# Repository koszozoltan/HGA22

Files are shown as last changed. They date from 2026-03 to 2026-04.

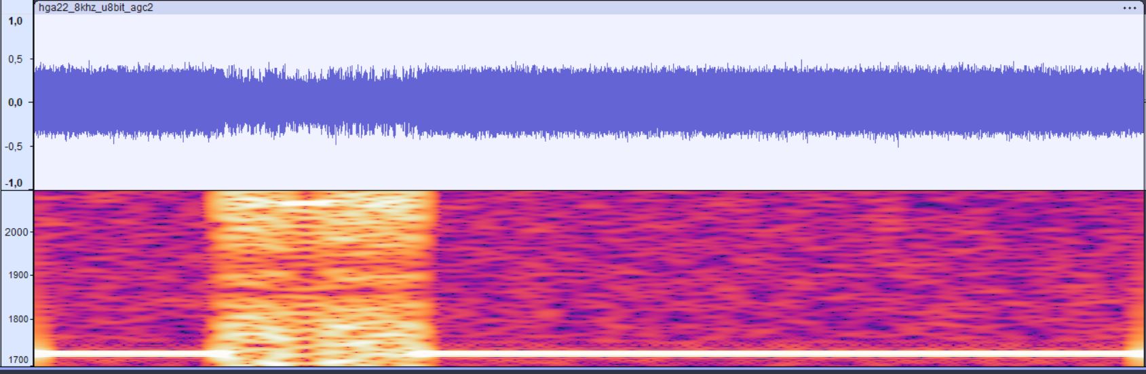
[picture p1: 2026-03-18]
docs/hga22_8khz_u8bit_agc2.jpg

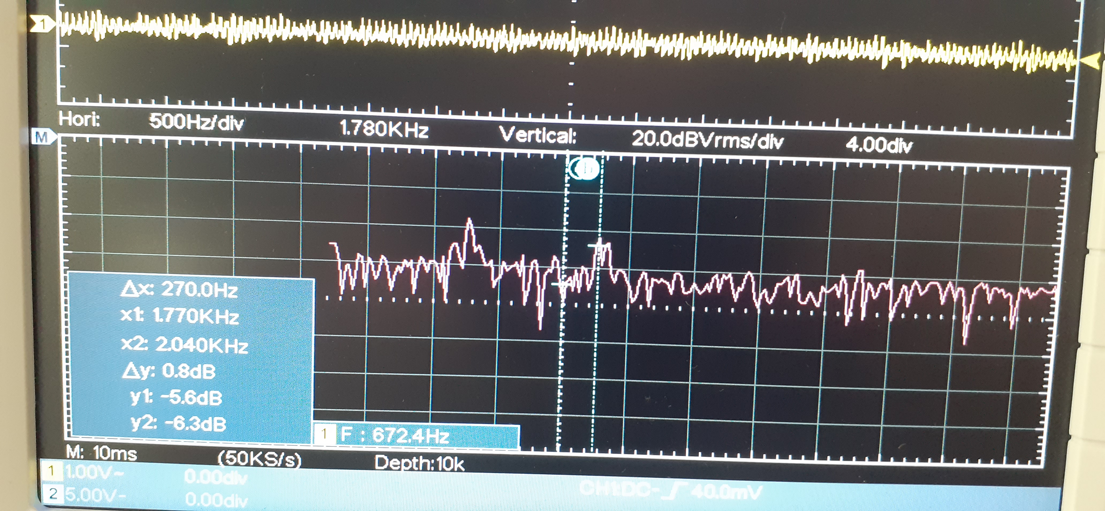
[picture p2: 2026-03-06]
docs/20260227_095744.jpg

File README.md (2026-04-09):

HGA22 Time Signal Receiver
This project is used to receive and decode the time signals broadcasted at 135.6 kHz by the HGA22 transmitter station in Lakihegy. The system is capable of processing phase-shift keying (FSK) signals and extracting time information.

https://github.com/5an2i/USB_HGA22

📋 Features
Frequency: 135.6 kHz (LF band)

Modulation: FSK

Platform: STM32C071 Nucleo
Data format: Serial, RNDIS USB - NTP
🛠️ Hardware architecture
The following components were required for reception:

Antenna: [Ferrite rod or RFID reader antenna] tuned to 135.6 kHz.

HGA22 Time Signal Receiver
Ez a projekt a lakihegyi HGA22 adóállomás 135,6 kHz-en sugárzott pontos idő jeleinek vételére és dekódolására szolgál. A rendszer képes a fázismodulált (FSK) jelek feldolgozására és az időinformáció kinyerésére.

📋 Jellemzők
Frekvencia: 135,6 kHz (LF sáv)

Moduláció: FSK

Platform: STM32C071 Nucleo
Adatformátum: Soros , RNDIS USB - NTP 
🛠️ Hardver felépítés
A vételhez az alábbi komponensekre volt szükség:

Antenna: [Ferrit rúd vagy RFID olvasó antenna] 135,6 kHz-re hangolva.

1. Mi az a HGA22?
A HGA22 egy hosszúhullámú (LF) rádióadó Lakihegyen, amely 135,6 kHz-en sugároz. Ez az EFR (Europäische Funk-Rundsteuerung) hálózat része, amit elsősorban távvezérlésre (pl. utcai világítás, „éjszakai áram”) és pontos idő szinkronizációra használnak.

Frekvencia: 135,6 kHz

Adatsebesség: 200 bps (Baud)

Szerepe: Alternatíva a német DCF77-re, de nagyobb adatsebességgel és gyakrabban küldött időinformációval rendelkezik (akár 10 másodpercenként).

2. A Moduláció: FSK (Frequency Shift Keying)
A digitális adatokat frekvenciabillentyűzéssel kódolják. Ez azt jelenti, hogy a logikai '0' és '1' szinteket két különböző frekvencia képviseli a vivőfrekvencia körül.

Shift (löket): ±170 Hz

Frekvenciák: * F_low: 135,430 kHz (Space / 0)

F_high: 135,770 kHz (Mark / 1)
A vevő dolga, hogy eldöntse: éppen melyik frekvencia „szól”.

3. A Matematikai Motor: Goertzel-algoritmus
Hogyan detektáljunk egy konkrét frekvenciát kevés számítási kapacitással? Itt jön a Goertzel-algoritmus. Ez egy speciális IIR (Infinite Impulse Response) szűrő, amely a Diszkrét Fourier-transzformáció (DFT) egyetlen komponensét számolja ki.

Miért jobb, mint az FFT?
Mivel nekünk csak két konkrét frekvenciát (a löket alatti és feletti értékeket) kell figyelnünk, felesleges a teljes spektrumot kiszámolni. A Goertzel sokkal gyorsabb mikrokontrolleren.

A kódunkban két Goertzel szűrő fut párhuzamosan. Amelyik kimenetén nagyobb az „energia” (amplitúdó), azt a bitet tekintjük érvényesnek.

4. HGA22 Frame Parsolás (Keretezés)
Az adatok nem ömlesztve jönnek, hanem kötött szerkezetű táviratokban (frames). A protokoll (hasonlóan a Versacom-hoz) az alábbi módon épül fel:

Start karakter: 0x68 (ez jelzi a csomag elejét).

Hossz: Megadja, hány bájt következik.

Ismételt Hossz és Start: Biztonsági ellenőrzés.

Címzés: Megadja, kinek szól az üzenet (az időjel címe általában 0x00).

Adat (Payload): Itt van a lényeg! BCD kódolással tartalmazza az évet, hónapot, napot, órát, percet és másodpercet.

Checksum (CRC): Hibaellenőrzés.

Stop karakter: 0x16.

A kódban (main.cpp):
A parsoló egy állapotgépet (State Machine) használ. Addig dobálja el a bejövő bájtokat, amíg nem talál egy 0x68-at, majd elkezdi feltölteni a puffert a megadott hossz alapján.

https://cmake.org/download/

https://www.codeblocks.org/

https://developer.arm.com/downloads/-/arm-gnu-toolchain-downloads

https://sourceforge.net/projects/gnuwin32/

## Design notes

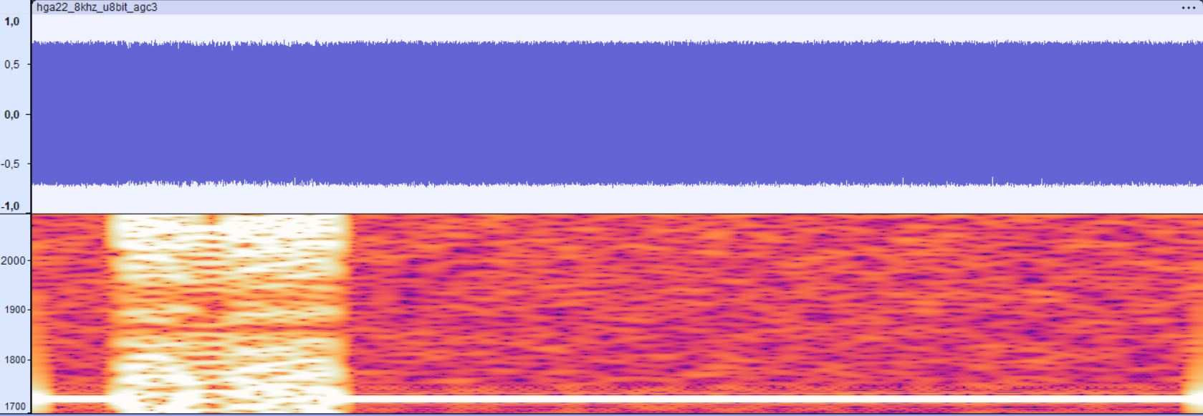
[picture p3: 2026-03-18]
docs/hga22_8khz_u8bit_agc3.jpg

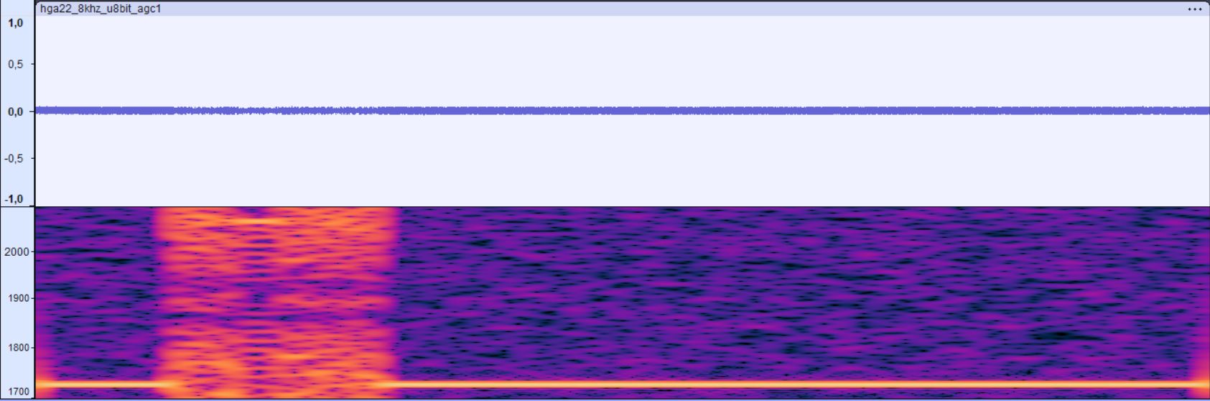
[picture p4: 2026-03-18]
docs/hga22_8khz_u8bit_agc1.jpg

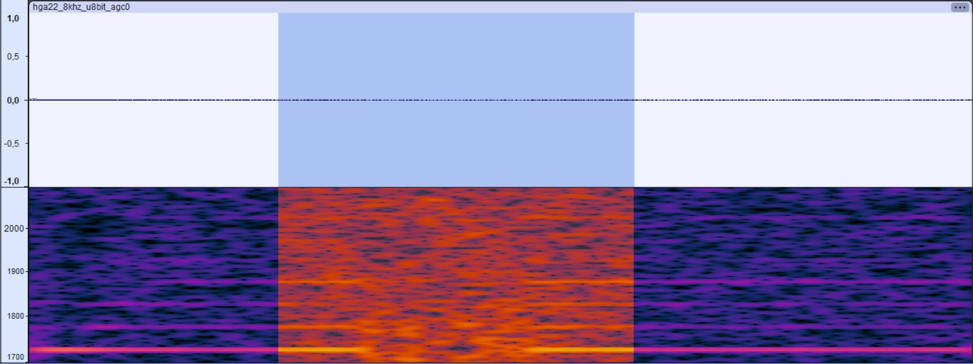
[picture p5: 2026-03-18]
docs/hga22_8khz_u8bit_agc0.jpg

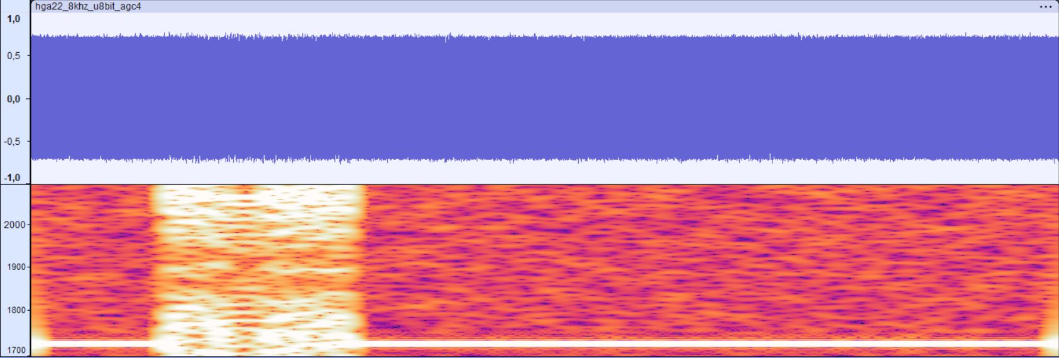
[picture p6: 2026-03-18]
docs/hga22_8khz_u8bit_agc4.jpg

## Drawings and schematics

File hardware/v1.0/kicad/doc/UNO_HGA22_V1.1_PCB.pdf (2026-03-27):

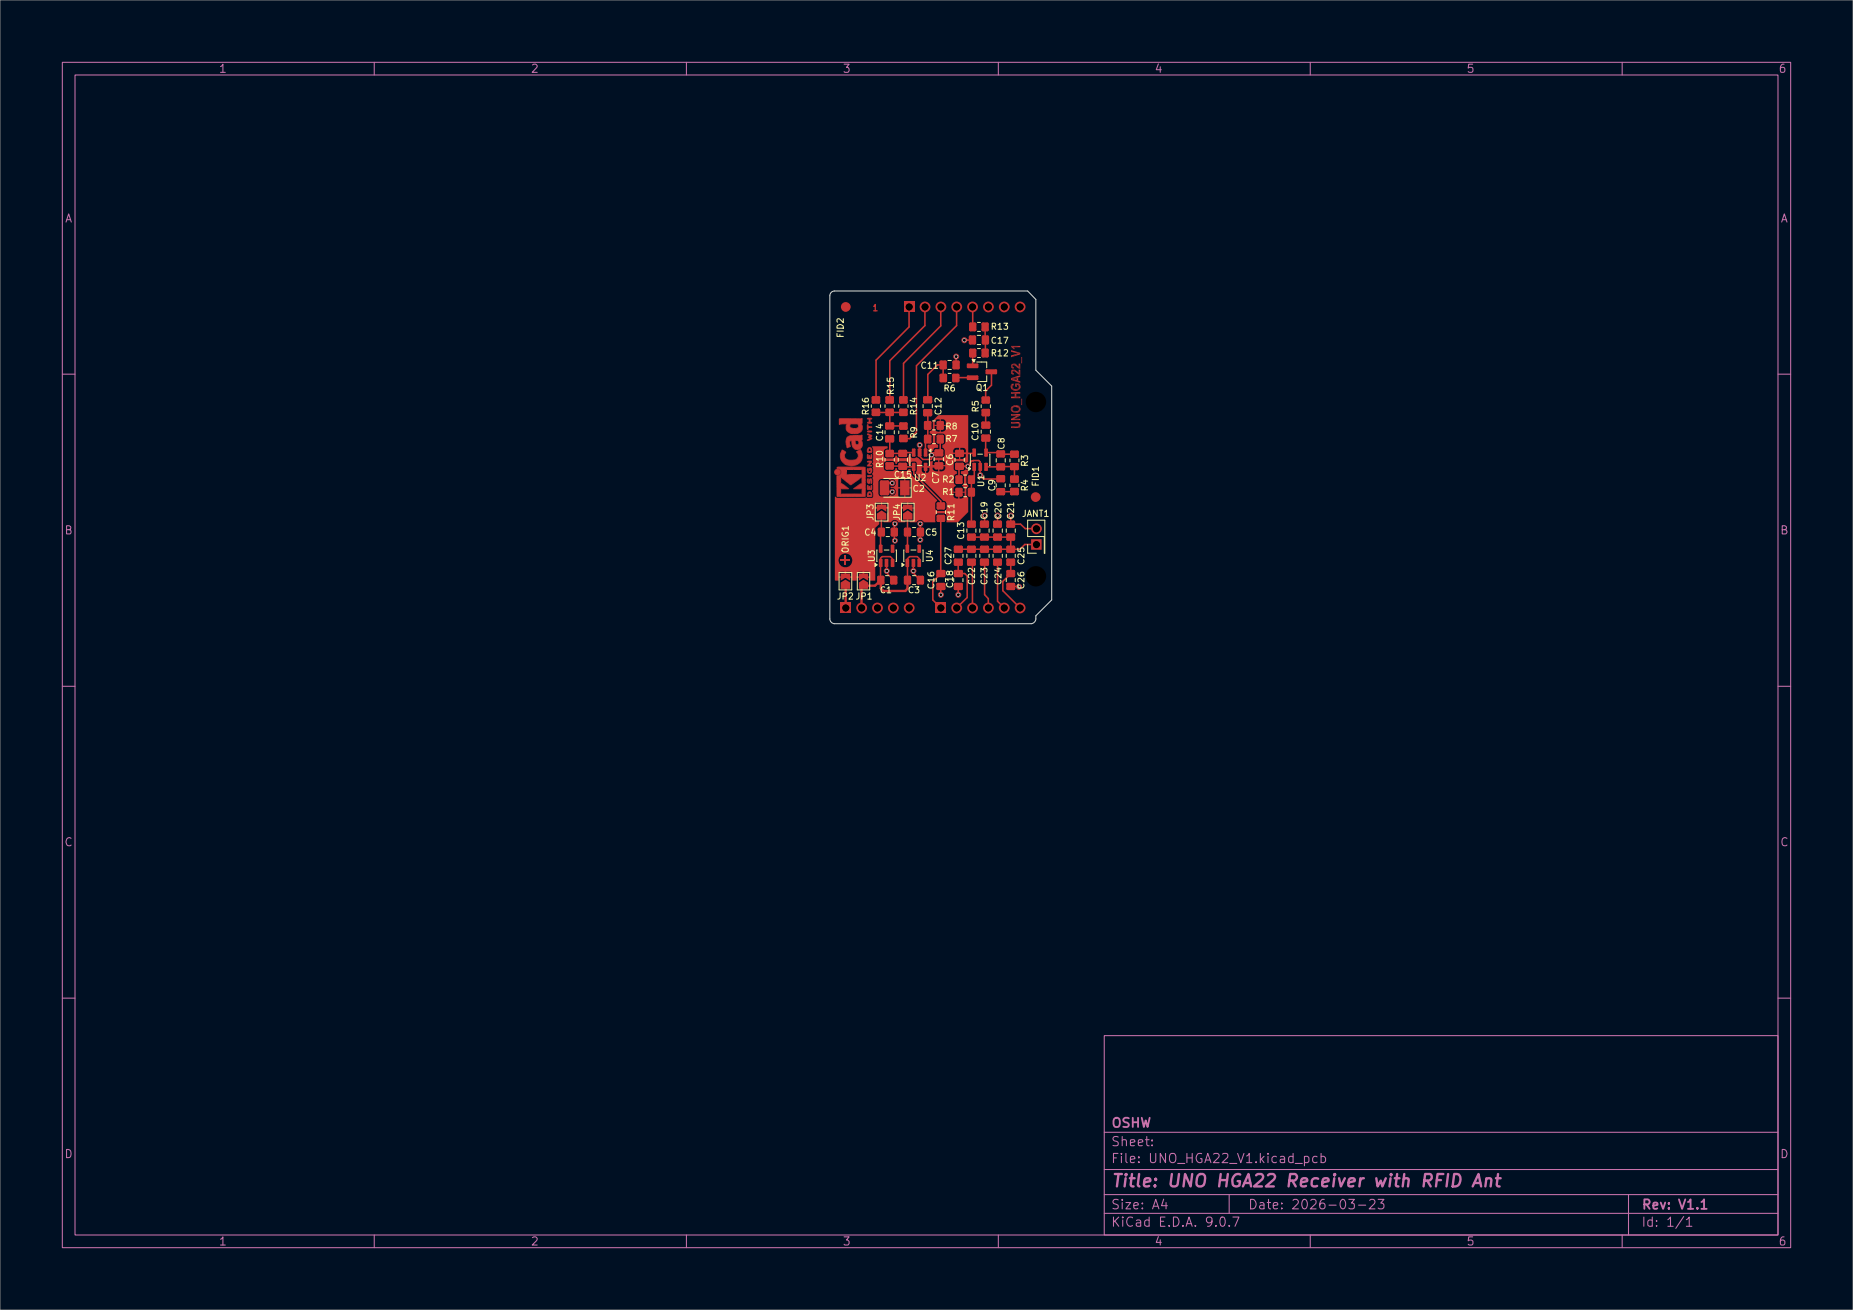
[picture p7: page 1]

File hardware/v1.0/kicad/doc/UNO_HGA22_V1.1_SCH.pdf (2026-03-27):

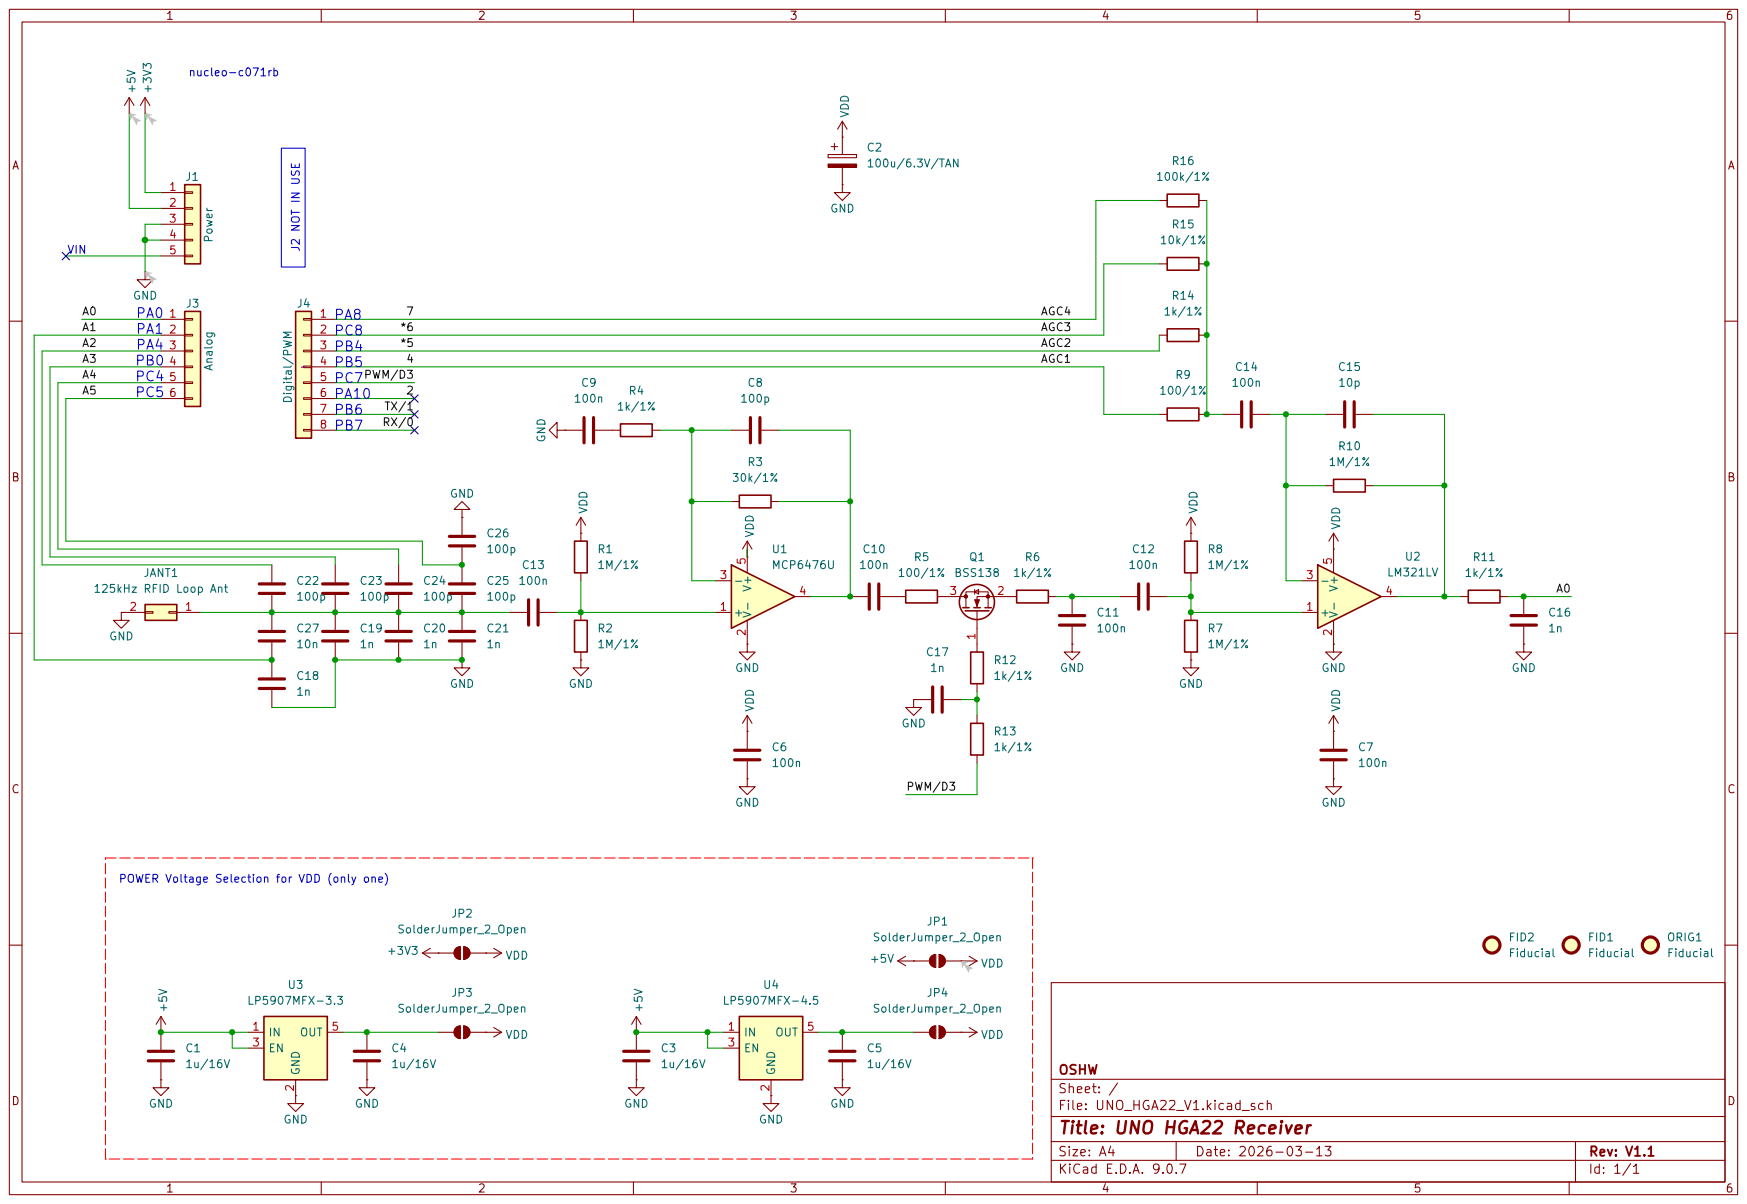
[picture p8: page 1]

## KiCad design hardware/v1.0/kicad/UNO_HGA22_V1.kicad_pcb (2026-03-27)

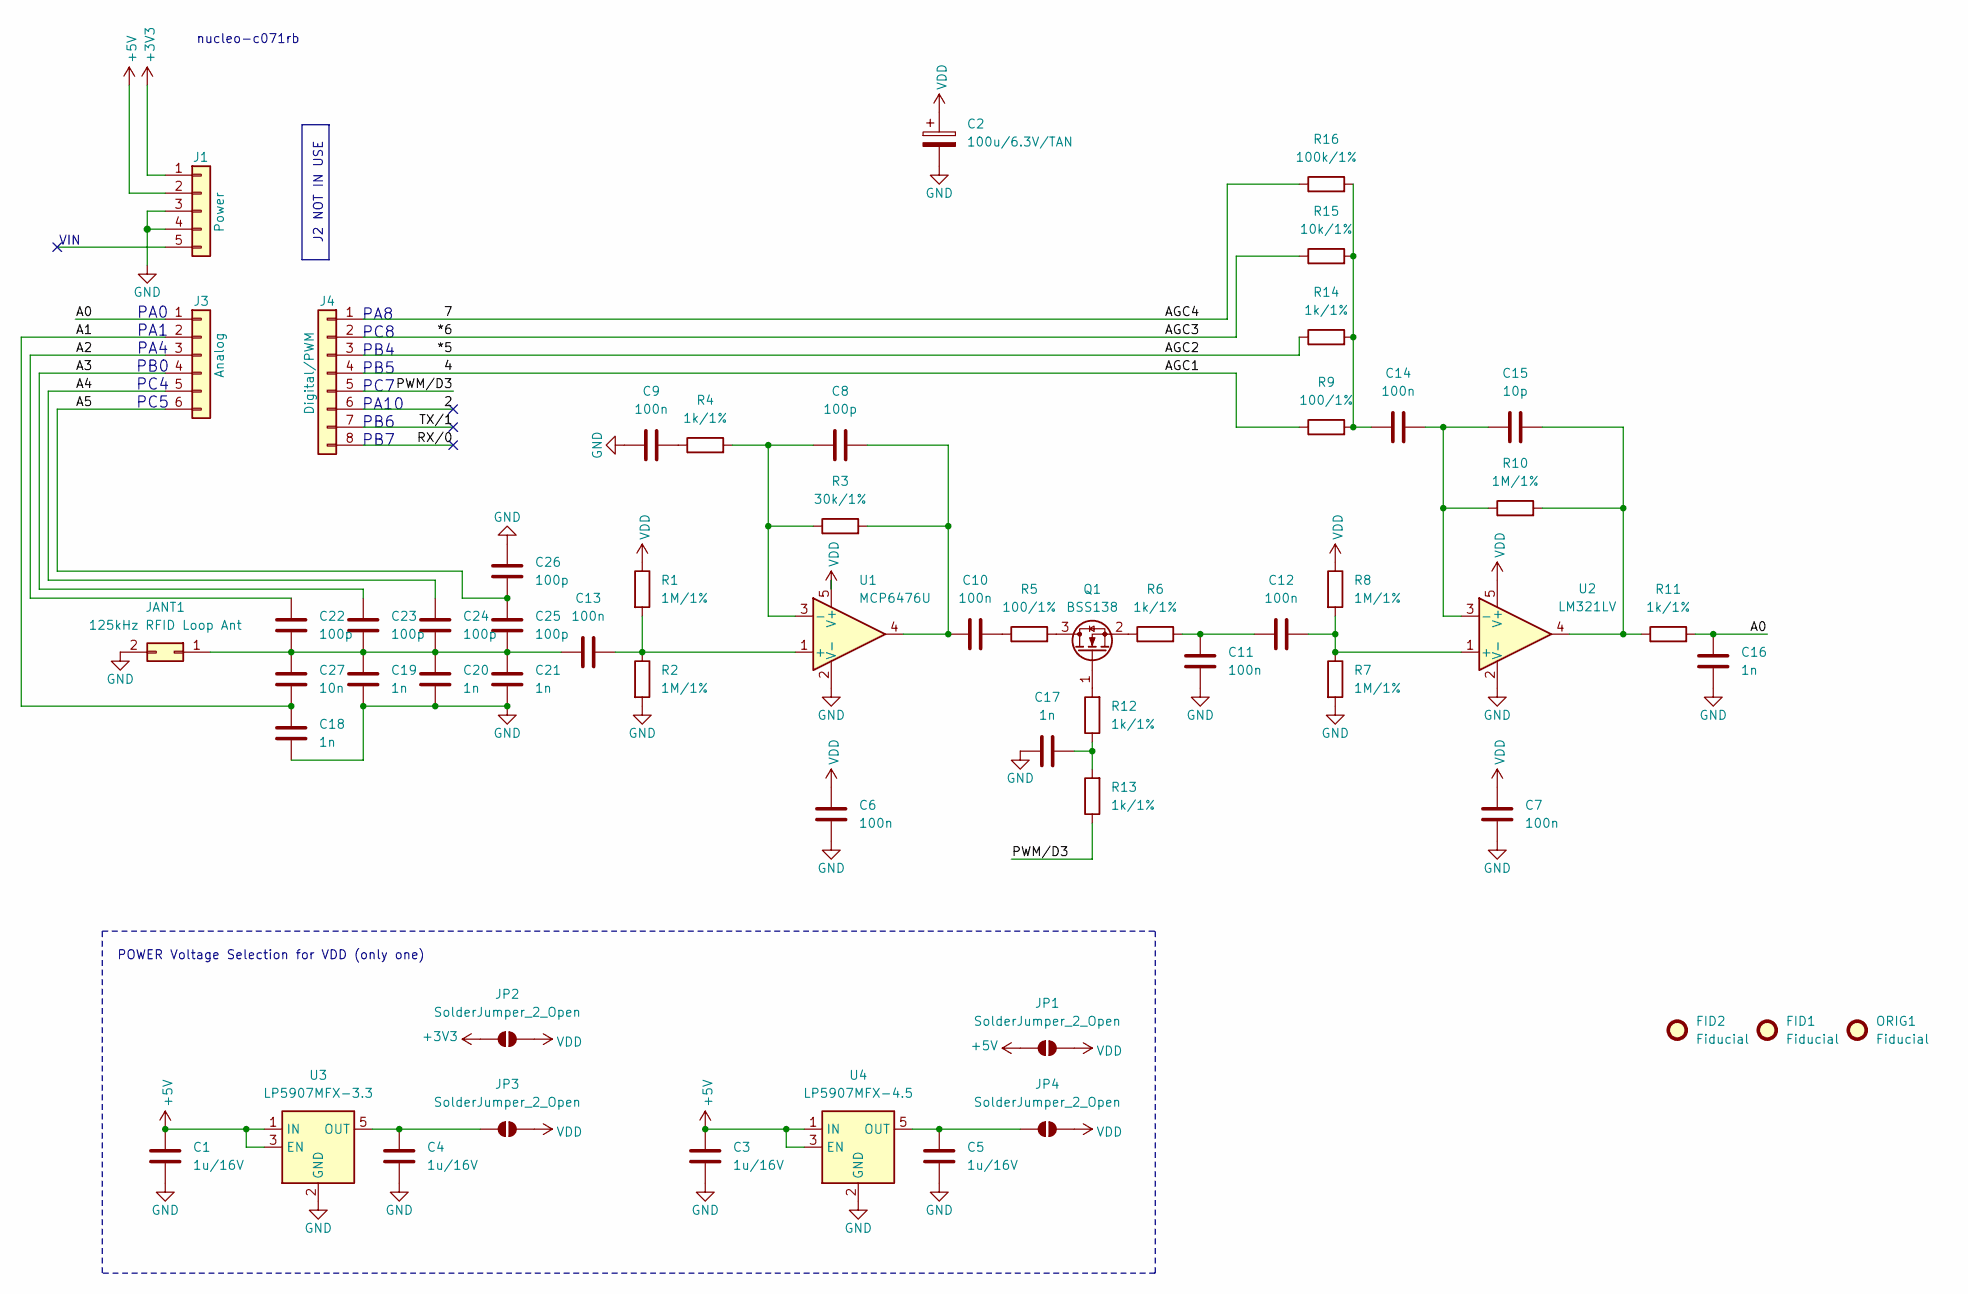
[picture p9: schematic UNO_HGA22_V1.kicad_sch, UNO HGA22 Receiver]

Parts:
C1, C3, C4, C5: 1u/16V; C_0805_2012Metric_Pad1.18x1.45mm_HandSolder
C2: 100u/6.3V/TAN; CP_EIA-3528-21_Kemet-B_HandSolder
C6, C7, C9, C10, C11, C12, C13, C14: 100n; C_0805_2012Metric_Pad1.18x1.45mm_HandSolder
C8, C22, C23, C24, C25, C26: 100p; C_0805_2012Metric_Pad1.18x1.45mm_HandSolder
C15: 10p; C_0805_2012Metric_Pad1.18x1.45mm_HandSolder
C16, C17, C18, C19, C20, C21: 1n; C_0805_2012Metric_Pad1.18x1.45mm_HandSolder
C27: 10n; C_0805_2012Metric_Pad1.18x1.45mm_HandSolder
FID1, FID2: Fiducial; Fiducial_1.5mm_Mask3mm
J1: Power; PinHeader_1x05_P2.54mm_Vertical
J3: Analog; PinHeader_1x06_P2.54mm_Vertical
J4: Digital/PWM; PinHeader_1x08_P2.54mm_Vertical
JANT1: 125kHz RFID Loop Ant; PinHeader_2x01_P2.54mm_Vertical
JP1, JP2, JP3, JP4: SolderJumper_2_Open; SolderJumper-2_P1.3mm_Open_TrianglePad1.0x1.5mm
ORIG1: Fiducial; Fiducial_Cross_1.5mm_Mask2mm
Q1: BSS138; SOT-23_Handsoldering
R1, R2, R7, R8, R10: 1M/1%; R_0805_2012Metric_Pad1.20x1.40mm_HandSolder
R3: 30k/1%; R_0805_2012Metric_Pad1.20x1.40mm_HandSolder
R4, R6, R11, R12, R13, R14: 1k/1%; R_0805_2012Metric_Pad1.20x1.40mm_HandSolder
R5, R9: 100/1%; R_0805_2012Metric_Pad1.20x1.40mm_HandSolder
R15: 10k/1%; R_0805_2012Metric_Pad1.20x1.40mm_HandSolder
R16: 100k/1%; R_0805_2012Metric_Pad1.20x1.40mm_HandSolder
U1: MCP6476U; SOT-23-5
U2: LM321LV; SOT-23-5
U3: LP5907MFX-3.3; SOT-23-5
U4: LP5907MFX-4.5; SOT-23-5

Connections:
+3V3: J1.1, JP2.1 (A)
+5V: C1.1, C3.1, J1.2, JP1.1 (A), U3.1 (IN), U3.3 (EN), U4.1 (IN), U4.3 (EN)
/2: J4.6
/4: J4.4, R9.1
/7: J4.1, R16.1
/*5: J4.3, R14.1
/*6: J4.2, R15.1
/A0: C16.1, J3.1, R11.2
/A1: C18.1, C27.2, J3.2
/A2: C22.2, J3.3
/A3: C23.2, J3.4
/A4: C24.2, J3.5
/A5: C25.2, C26.1, J3.6
/PWM/D3: J4.5, R13.1
/RX/0: J4.8
/TX/1: J4.7
GND: C1.2, C2.2, C3.2, C4.2, C5.2, C6.2, C7.2, C9.1, C11.2, C16.2, C17.1, C18.2, C19.2, C20.2, C21.2, C26.2, J1.3, J1.4, JANT1.2, R2.2, R7.2, U1.2 (V-), U2.2 (V-), U3.2 (GND), U4.2 (GND)
unnamed: C9.2, R4.1
unnamed: C8.2, C10.1, R3.2, U1.4
unnamed: C10.2, R5.1
unnamed: C11.1, C12.1, R6.2
unnamed: C14.1, R9.2, R14.2, R15.2, R16.2
unnamed: C15.2, R10.2, R11.1, U2.4
unnamed: C17.2, R12.1, R13.2
unnamed: C13.1, C19.1, C20.1, C21.1, C22.1, C23.1, C24.1, C25.1, C27.1, JANT1.1
unnamed: C4.1, JP3.1 (A), U3.5 (OUT)
unnamed: C5.1, JP4.1 (A), U4.5 (OUT)
unnamed: Q1.3 (D), R5.2
unnamed: Q1.1 (G), R12.2
unnamed: Q1.2 (S), R6.1
unnamed: C13.2, R1.2, R2.1, U1.1 (+)
unnamed: C8.1, R3.1, R4.2, U1.3 (-)
unnamed: C12.2, R7.1, R8.2, U2.1 (+)
unnamed: C14.2, C15.1, R10.1, U2.3 (-)
VDD: C2.1, C6.1, C7.1, JP1.2 (B), JP2.2 (B), JP3.2 (B), JP4.2 (B), R1.1, R8.1, U1.5 (V+), U2.5 (V+)

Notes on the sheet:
J2 NOT IN USE
PA0 PA1 PA4 PB0 PC4 PC5
VIN
PA8 PC8 PB4 PB5 PC7 PA10 PB6 PB7
POWER Voltage Selection for VDD (only one)
nucleo-c071rb

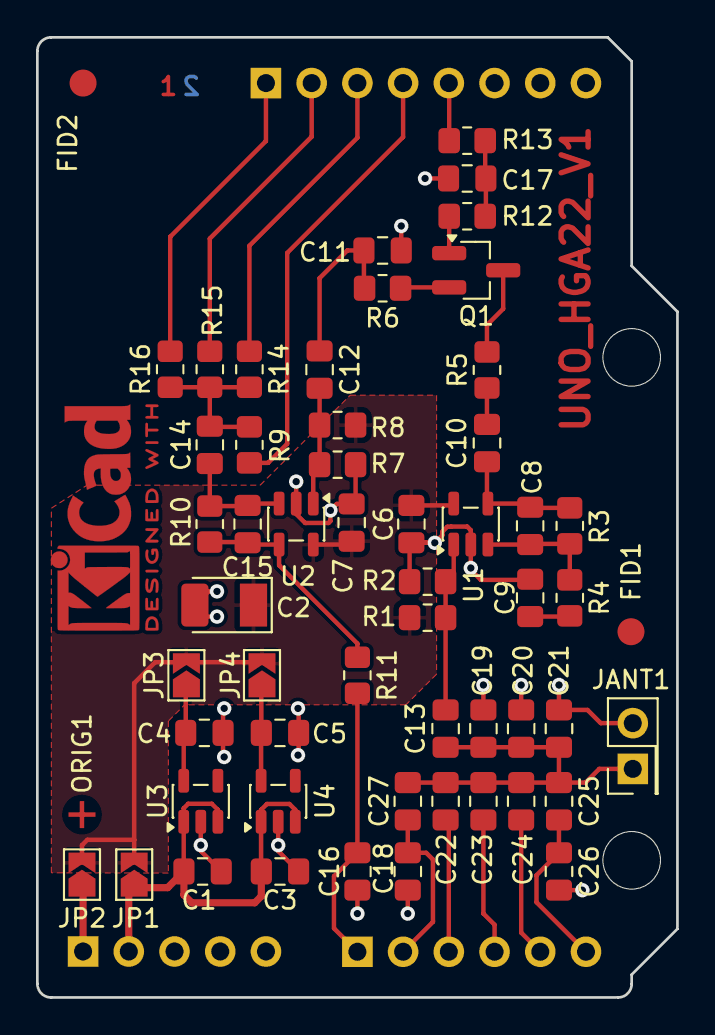
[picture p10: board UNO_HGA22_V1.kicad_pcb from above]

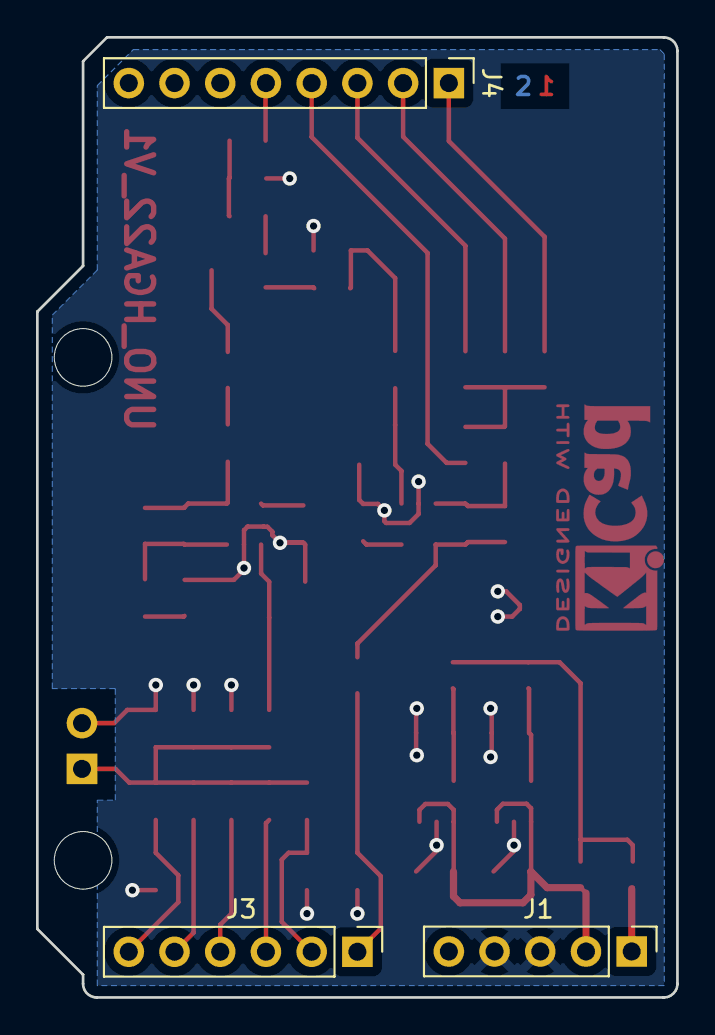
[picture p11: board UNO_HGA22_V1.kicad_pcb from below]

Board: 2 copper layers, 35.6 x 53.3 mm, 61 parts (3 on the bottom side), 32 nets.

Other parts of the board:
MH3, MH4: MountingHole_3.2mm

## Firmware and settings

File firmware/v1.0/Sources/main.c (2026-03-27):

/* USER CODE BEGIN Header */
/**
  ******************************************************************************
  * @file    UART/UART_Printf/Src/main.c
  * @author  MCD Application Team
  * @brief   This example shows how to retarget the C library printf function
  *          to the UART.
  ******************************************************************************
  * @attention
  *
  * Copyright (c) 2024 STMicroelectronics.
  * All rights reserved.
  *
  * This software is licensed under terms that can be found in the LICENSE file
  * in the root directory of this software component.
  * If no LICENSE file comes with this software, it is provided AS-IS.
  *
  ******************************************************************************
  */

/* Includes ------------------------------------------------------------------*/
#include "main.h"
#include "util.h"
#include <string.h>
#include "queue.h"
#include "math.h"
#include "ringbuffer.h"
#include "tcp_server.h"
#include "arm_math.h"
#include "date.h"
#include "adc.h"
#include "iq.h"
#include "goertzel.h"
#include "decoder.h"








UART_HandleTypeDef huart2;

__IO uint32_t uwMeasuredDutyCycle = 0;

/* TIM2 Clock */
static uint32_t TimOutClock = 1;
uint32_t timxPrescaler = 0;
uint32_t timxPeriod = 0;

void Error_Handler2(int);
static void SystemClockHSIUSB48_Config(void);
static inline void board_clock_init(void) ;

int cap = 0;
int agc = 0;
float snr = 0;
int send_array = 0;
int send_snr   = 0;
int search = 0;



int agc_disable = 0;
int min = 65536;
int max = -1;




volatile uint64_t unix_us = 0;// += 1000ULL;


void SystemClock_Config(void);
static void MX_GPIO_Init(void);
static void MX_USART2_UART_Init(void);
static void Timer3Init(void);

/* USER CODE BEGIN PFP */

void ADC_Init(void);
void ADC_Activate(void);
void LED_On(void);
void LED_Off(void);
void LED_Toggle(void);


void RFC1_low(void);
void RFC1_high(void);
void RFC2_low(void);
void RFC2_high(void);
void RFC3_low(void);
void RFC3_high(void);
void RFC4_low(void);
void RFC4_high(void);



void unix_us_to_datetime(uint64_t unix_us, datetime_t *dt);
uint64_t datetime_to_unix_us(const datetime_t *dt, uint32_t usec);

extern void udp_server_init(void);
extern void ShellTask(void);

int Get_HW_Agc(void);



#define PUTCHAR_PROTOTYPE int __io_putchar(int ch)












uint16_t signal_buffer[128];
stream_q_t q_signal;




size_t board_get_unique_id(uint8_t id[], size_t max_len) {
  (void) max_len;
  volatile uint32_t * stm32_uuid = (volatile uint32_t *) UID_BASE;
  uint32_t* id32 = (uint32_t*) (uintptr_t) id;
  uint8_t const len = 12;

  id32[0] = stm32_uuid[0];
  id32[1] = stm32_uuid[1];
  id32[2] = stm32_uuid[2];

  return len;
}






extern void loop_tinyusb (void);
extern int main_tinyusb(void);

//void init_demods(void);


/**
  * @brief  The application entry point.
  * @retval int
  */
int main(void)
{

  HAL_Init();
  BSP_LED_Init(LED1);
  BSP_LED_Init(LED2);
  //SystemClockHSIUSB48_Config() ;
  board_clock_init();

  HAL_Init();


  sq_init(&q_signal, (int16_t*)signal_buffer, 128);
 // sq_init(&q_byte,   (int16_t*)byte_buffer, 32);
 // sq_init(&q_fsk,    (int16_t*)fsk_buffer, 8);
  #if 0
  sq_init(&q_voice,voice_buffer,8192);
  #endif




  MX_GPIO_Init();
  MX_USART2_UART_Init();
  Timer3Init();


  ADC_Init();





  Uart2_printf("\r\nHGA22 RECEIVER RNDIS V1.0>\r\n");
  Uart2_printf("%s %s\r\n", BUILD_DATE);

  Uart2_rx_printf("-h\r\n");
  Uart2_rx_printf("?\r\n");


  {
	  datetime_t dt;

	   dt.yr  = 2026;
	   dt.mon = 1;
	   dt.day = 1;
	   dt.hr  = 0;
	   dt.min = 0;
	   dt.sec = 0;

	   uint64_t now = datetime_to_unix_us(&dt, 0);

	   /* RTC -> dt mezők feltöltése */
	   NVIC_DisableIRQ(SysTick_IRQn);
	   unix_us = now;
	   NVIC_EnableIRQ(SysTick_IRQn);
  }


  RFC1_low();
  RFC2_low();
  RFC3_low();
  RFC4_low();

  AGC1_high();
  AGC2_high();
  AGC3_low();
  AGC4_low();

	__HAL_RCC_USB_CLK_ENABLE();
	__HAL_RCC_GPIOA_CLK_ENABLE();
	__HAL_RCC_GPIOB_CLK_ENABLE();
	__HAL_RCC_GPIOC_CLK_ENABLE();
	__HAL_RCC_GPIOD_CLK_ENABLE();
	__HAL_RCC_SYSCFG_CLK_ENABLE();
	__HAL_RCC_PWR_CLK_ENABLE();
#if 1
  main_tinyusb();
  udp_server_init();

#endif

init_demods();


  while(1){

	  ShellTask();

	  loop_tinyusb();


	  if(ubDmaTransferStatus == 1) {
		  //LED_On();




		  static int send_snr_cnt = 0;
		  if (send_snr){
			  if (++send_snr_cnt >= 1000){
				  send_snr_cnt = 0;
				  Uart2_printf("SNR : %d , min %d, max %d\r\n", (int)snr, (int)min, (int) max );
			  }
		  }

		  static int buffer_size = (SAMPLE_RATE / 1000) * 4;

		   if (sq_size(&q_signal) >= buffer_size){

			   int16_t buffer[buffer_size];


			   sq_peek(&q_signal,buffer,buffer_size);
			   sq_discard(&q_signal,(SAMPLE_RATE / 1000));

			   if (search){
                    if (++send_snr_cnt >= 200){
                        send_snr_cnt = 0;
                        search_freq((uint16_t *)buffer,buffer_size);
                    }
			   }

			   loop(buffer,(SAMPLE_RATE / 1000) * 4);
			   //LED_Off();

		   }

		  //LED_Off();
		  ubDmaTransferStatus = 0;
	  }


  }


}

uint32_t board_button_read(void) {
	return USER_BUTTON_STATE_ACTIVE == HAL_GPIO_ReadPin(USER_BUTTON_GPIO_Port, USER_BUTTON_Pin);
}



static void MX_TIM3_Init(void) {



  LL_TIM_InitTypeDef TIM_InitStruct = {0};
  LL_TIM_OC_InitTypeDef TIM_OC_InitStruct = {0};

  LL_GPIO_InitTypeDef GPIO_InitStruct = {0};

  /* Peripheral clock enable */
  LL_APB1_GRP1_EnableClock(LL_APB1_GRP1_PERIPH_TIM3);

  TIM_InitStruct.Prescaler = timxPrescaler;
  TIM_InitStruct.CounterMode = LL_TIM_COUNTERMODE_UP;
  TIM_InitStruct.Autoreload = timxPeriod;
  TIM_InitStruct.ClockDivision = LL_TIM_CLOCKDIVISION_DIV1;
  LL_TIM_Init(TIM3, &TIM_InitStruct);
  LL_TIM_EnableARRPreload(TIM3);
  LL_TIM_OC_EnablePreload(TIM3, LL_TIM_CHANNEL_CH2);
  TIM_OC_InitStruct.OCMode = LL_TIM_OCMODE_PWM1;
  TIM_OC_InitStruct.OCState = LL_TIM_OCSTATE_DISABLE;
  TIM_OC_InitStruct.OCNState = LL_TIM_OCSTATE_DISABLE;
  TIM_OC_InitStruct.CompareValue = ((timxPeriod + 1 ) / 2);
  TIM_OC_InitStruct.OCPolarity = LL_TIM_OCPOLARITY_HIGH;
  LL_TIM_OC_Init(TIM3, LL_TIM_CHANNEL_CH2, &TIM_OC_InitStruct);
  LL_TIM_OC_DisableFast(TIM3, LL_TIM_CHANNEL_CH2);
  LL_TIM_SetTriggerOutput(TIM3, LL_TIM_TRGO_RESET);
  LL_TIM_DisableMasterSlaveMode(TIM3);

  LL_IOP_GRP1_EnableClock(LL_IOP_GRP1_PERIPH_GPIOA);
  LL_IOP_GRP1_EnableClock(LL_IOP_GRP1_PERIPH_GPIOC);

  GPIO_InitStruct.Pin = TIM3_CH2_Pin;
  GPIO_InitStruct.Mode = LL_GPIO_MODE_ALTERNATE;
  GPIO_InitStruct.Speed = LL_GPIO_SPEED_FREQ_LOW;
  GPIO_InitStruct.OutputType = LL_GPIO_OUTPUT_PUSHPULL;
  GPIO_InitStruct.Pull = LL_GPIO_PULL_DOWN;
  GPIO_InitStruct.Alternate = LL_GPIO_AF_1;
  LL_GPIO_Init(TIM3_CH2_GPIO_Port, &GPIO_InitStruct);

}


static void Timer3Init(void) {

 /* - Set the pre-scaler value to have TIM3 counter clock equal to 10 kHz  */
 /* - Set the auto-reload value to have a counter frequency of 100 Hz        */
 /* TIM3CLK = SystemCoreClock / (APB prescaler & multiplier)               */
 TimOutClock = SystemCoreClock/1;
 timxPrescaler = __LL_TIM_CALC_PSC (SystemCoreClock, 80000000);
 timxPeriod = __LL_TIM_CALC_ARR    (TimOutClock,     timxPrescaler,   TIMER3_FREQ);

 /* Initialize all configured peripherals */
 MX_TIM3_Init();


 /**************************/
 /* TIM3 interrupts set-up */
 /**************************/
 /* Enable the capture/compare interrupt for channel 1 */
 LL_TIM_EnableIT_CC1(TIM3);

 /**********************************/
 /* Start output signal generation */
 /**********************************/
 /* Enable output channel 1 */
 LL_TIM_CC_EnableChannel(TIM3, LL_TIM_CHANNEL_CH2);

 /* Enable counter */
 LL_TIM_EnableCounter(TIM3);

 /* Force update generation */
 LL_TIM_GenerateEvent_UPDATE(TIM3);
}



static void SystemClockHSIUSB48_Config(void)
{

  //RCC_OscInitTypeDef RCC_OscInitStruct = {0};
  RCC_ClkInitTypeDef RCC_ClkInitStruct = {0};
  RCC_CRSInitTypeDef RCC_CRSInitStruct = {0};
  RCC_PeriphCLKInitTypeDef PeriphClkInit = {0};

  __HAL_FLASH_SET_LATENCY(FLASH_LATENCY_1);

  /** Initializes the RCC Oscillators according to the specified parameters
  * in the RCC_OscInitTypeDef structure.
  */



   {


      RCC_OscInitTypeDef RCC_OscInitStruct = {0};
      RCC_OscInitStruct.OscillatorType = RCC_OSCILLATORTYPE_HSI48;
      RCC_OscInitStruct.HSI48State = RCC_HSI48_ON;

      if (HAL_RCC_OscConfig(&RCC_OscInitStruct) != HAL_OK)
      {
        Error_Handler2(3);

      }

  }



  /** Initializes the CPU, AHB and APB buses clocks
  */
  RCC_ClkInitStruct.ClockType = RCC_CLOCKTYPE_HCLK|RCC_CLOCKTYPE_SYSCLK
                              |RCC_CLOCKTYPE_PCLK1;
  RCC_ClkInitStruct.SYSCLKSource = RCC_SYSCLKSOURCE_HSIUSB48;
  RCC_ClkInitStruct.SYSCLKDivider = RCC_SYSCLK_DIV1;
  RCC_ClkInitStruct.AHBCLKDivider = RCC_HCLK_DIV1;
  RCC_ClkInitStruct.APB1CLKDivider = RCC_APB1_DIV1;

  if (HAL_RCC_ClockConfig(&RCC_ClkInitStruct, FLASH_LATENCY_1) != HAL_OK)
  {
    Error_Handler2(5);
  }

  /** Enable the CRS APB clock
  */
  __HAL_RCC_CRS_CLK_ENABLE();

  /** Configures CRS
  */
  RCC_CRSInitStruct.Prescaler = RCC_CRS_SYNC_DIV1;
  RCC_CRSInitStruct.Source = RCC_CRS_SYNC_SOURCE_USB;
  RCC_CRSInitStruct.Polarity = RCC_CRS_SYNC_POLARITY_RISING;
  RCC_CRSInitStruct.ReloadValue = __HAL_RCC_CRS_RELOADVALUE_CALCULATE(48000000,1000);
  RCC_CRSInitStruct.ErrorLimitValue = 34;
  RCC_CRSInitStruct.HSI48CalibrationValue = 32;

  HAL_RCCEx_CRSConfig(&RCC_CRSInitStruct);


  PeriphClkInit.PeriphClockSelection = RCC_PERIPHCLK_USB;
  PeriphClkInit.UsbClockSelection = RCC_USBCLKSOURCE_HSI48;
  HAL_RCCEx_PeriphCLKConfig(&PeriphClkInit);

  LL_Init1msTick(48000000);
  /* Update CMSIS variable (which can be updated also through SystemCoreClockUpdate function) */
  LL_SetSystemCoreClock(48000000);

}

static inline void board_clock_init(void) {
  RCC_OscInitTypeDef RCC_OscInitStruct = {0};
  RCC_ClkInitTypeDef RCC_ClkInitStruct = {0};
  RCC_PeriphCLKInitTypeDef PeriphClkInit = {0};

  __HAL_FLASH_SET_LATENCY(FLASH_LATENCY_1);

  /** Initializes the RCC Oscillators according to the specified parameters
  * in the RCC_OscInitTypeDef structure.
  */
  RCC_OscInitStruct.OscillatorType = RCC_OSCILLATORTYPE_HSE;
  RCC_OscInitStruct.HSEState = RCC_HSE_ON;
  HAL_RCC_OscConfig(&RCC_OscInitStruct);

  /** Initializes the CPU, AHB and APB buses clocks
  */
  RCC_ClkInitStruct.ClockType = RCC_CLOCKTYPE_HCLK|RCC_CLOCKTYPE_SYSCLK
                              |RCC_CLOCKTYPE_PCLK1;
  RCC_ClkInitStruct.SYSCLKSource = RCC_SYSCLKSOURCE_HSE;
  RCC_ClkInitStruct.SYSCLKDivider = RCC_SYSCLK_DIV1;
  RCC_ClkInitStruct.AHBCLKDivider = RCC_HCLK_DIV1;
  RCC_ClkInitStruct.APB1CLKDivider = RCC_APB1_DIV1;

  HAL_RCC_ClockConfig(&RCC_ClkInitStruct, FLASH_LATENCY_1);

  PeriphClkInit.PeriphClockSelection = RCC_PERIPHCLK_USB;
  PeriphClkInit.UsbClockSelection = RCC_USBCLKSOURCE_HSE;
  HAL_RCCEx_PeriphCLKConfig(&PeriphClkInit);

  LL_Init1msTick(48000000);
  /* Update CMSIS variable (which can be updated also through SystemCoreClockUpdate function) */
  LL_SetSystemCoreClock(48000000);

}


static void SystemClockHSE_Config(void) {

	board_clock_init();
	return;


  RCC_OscInitTypeDef RCC_OscInitStruct = {0};
  RCC_ClkInitTypeDef RCC_ClkInitStruct = {0};

  /* -1- Enable HSE  Oscillator */
  RCC_OscInitStruct.OscillatorType = RCC_OSCILLATORTYPE_HSE;
  RCC_OscInitStruct.HSEState = RCC_HSE_ON;
  if (HAL_RCC_OscConfig(&RCC_OscInitStruct) != HAL_OK)
  {
    Error_Handler();
  }

  /* -2- Initializes the CPU, AHB and APB buses clocks */
  RCC_ClkInitStruct.ClockType = RCC_CLOCKTYPE_HCLK|RCC_CLOCKTYPE_SYSCLK
                              |RCC_CLOCKTYPE_PCLK1;
  RCC_ClkInitStruct.SYSCLKSource = RCC_SYSCLKSOURCE_HSE;
  RCC_ClkInitStruct.SYSCLKDivider = RCC_SYSCLK_DIV1;
  RCC_ClkInitStruct.AHBCLKDivider = RCC_HCLK_DIV1;
  RCC_ClkInitStruct.APB1CLKDivider = RCC_APB1_DIV1;

  if (HAL_RCC_ClockConfig(&RCC_ClkInitStruct, FLASH_LATENCY_1) != HAL_OK)
  {
    Error_Handler();
  }
 /* -3- Optional: Disable HSIUSB48  Oscillator (if the HSIUSB48  is no more needed by the application) */
  RCC_OscInitStruct.OscillatorType                = RCC_OSCILLATORTYPE_HSI48;
  RCC_OscInitStruct.HSI48State                      = RCC_HSI48_OFF;
  if (HAL_RCC_OscConfig(&RCC_OscInitStruct) != HAL_OK)
  {
    /* Initialization Error */
    Error_Handler();
  }

  LL_Init1msTick(48000000);
  /* Update CMSIS variable (which can be updated also through SystemCoreClockUpdate function) */
  LL_SetSystemCoreClock(48000000);

}

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


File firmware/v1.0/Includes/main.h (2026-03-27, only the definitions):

#define USE_TIMEOUT       0
#define LED_BLINK_FAST       100  /* Toggle period fast (unit: ms) */
#define LED_BLINK_SLOW       500  /* Toggle period slow (unit: ms) */
#define LED_BLINK_ERROR     1000  /* Toggle period very slow for error case (unit: ms) */
#define USER_BUTTON_Pin 		LL_GPIO_PIN_13
#define USER_BUTTON_GPIO_Port 	GPIOC
#define USER_BUTTON_EXTI_IRQn 	EXTI4_15_IRQn
#define USER_BUTTON_STATE_ACTIVE   0
#define TIM3_CH1_Pin 			LL_GPIO_PIN_6
#define TIM3_CH1_GPIO_Port 		GPIOA
#define TIM3_CH2_Pin 			LL_GPIO_PIN_7
#define TIM3_CH2_GPIO_Port 		GPIOC
#define LED1_Pin 				LL_GPIO_PIN_5
#define LED1_GPIO_Port			 GPIOA
#define NVIC_PRIORITYGROUP_0         ((uint32_t)0x00000007) /*!< 0 bit  for pre-emption priority,
#define NVIC_PRIORITYGROUP_1         ((uint32_t)0x00000006) /*!< 1 bit  for pre-emption priority,
#define NVIC_PRIORITYGROUP_2         ((uint32_t)0x00000005) /*!< 2 bits for pre-emption priority,
#define NVIC_PRIORITYGROUP_3         ((uint32_t)0x00000004) /*!< 3 bits for pre-emption priority,
#define NVIC_PRIORITYGROUP_4         ((uint32_t)0x00000003) /*!< 4 bits for pre-emption priority,
#define RTC_ASYNCH_PREDIV    0x7F
#define RTC_SYNCH_PREDIV     0xFF
#define RTC_ASYNCH_PREDIV  0x7F
#define RTC_SYNCH_PREDIV   0x00FF
#define BUILD_DATE __DATE__ " " __TIME__

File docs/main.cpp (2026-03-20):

#include <fstream>
#include <iostream>
#include <vector>
#include <cmath>
#include <iomanip>
#include <stdexcept>
#include <climits>
#include <cstdint>

#ifndef SAMPLE_RATE
#define SAMPLE_RATE 8000
#endif

#ifndef ADC_MIDPOINT
#define ADC_MIDPOINT 128
#endif

#ifndef M_PI
#define M_PI 3.14159265358979323846
#endif

float adc_midpoint = ADC_MIDPOINT;

/* ========================= RingBuffer ========================= */

template<typename T>
class RingBuffer {
public:
    explicit RingBuffer(size_t capacity)
        : _capacity(capacity), _buffer(capacity), _head(0), _count(0) {}

    void push(const T& value) {
        _buffer[_head] = value;
        _head = (_head + 1) % _capacity;

        if (_count < _capacity) {
            ++_count;
        }
    }

    size_t size() const { return _count; }
    size_t capacity() const { return _capacity; }

    T& operator[](size_t index) {
        if (index >= _count) {
            throw std::out_of_range("RingBuffer index out of range");
        }
        size_t realIndex = (_head + _capacity - _count + index) % _capacity;
        return _buffer[realIndex];
    }

    const T& operator[](size_t index) const {
        if (index >= _count) {
            throw std::out_of_range("RingBuffer index out of range");
        }
        size_t realIndex = (_head + _capacity - _count + index) % _capacity;
        return _buffer[realIndex];
    }

    void clear() {
        _head = 0;
        _count = 0;
    }

private:
    size_t _capacity;
    std::vector<T> _buffer;
    size_t _head;
    size_t _count;
};

/* ========================= Goertzel ========================= */

class Goertzel {
public:
    Goertzel(float freq, int rate = SAMPLE_RATE);
    float Mag(int samples[], int depth);

private:
    float COEF;
};

Goertzel::Goertzel(float freq, int rate) {
    COEF = 2.0f * std::cos((2.0f * M_PI * freq) / rate);
}

float Goertzel::Mag(int samples[], int depth) {
    float Q1 = 0, Q2 = 0;

    for (int n = 0; n < depth; ++n) {
        float Q0 = COEF * Q1 - Q2 + (samples[n] - adc_midpoint);
        Q2 = Q1;
        Q1 = Q0;
    }

    return std::sqrt(Q1 * Q1 + Q2 * Q2 - COEF * Q1 * Q2);
}

/* ========================= Utils ========================= */

bool bit_to_byte(uint8_t bit, uint8_t* out_byte) {
    static uint8_t shift_reg = 0;
    static uint8_t bit_count = 0;

    shift_reg = (shift_reg >> 1) | (bit ? 0x80 : 0x00);
    ++bit_count;

    if (bit_count == 8) {
        *out_byte = shift_reg;
        bit_count = 0;
        shift_reg = 0;
        return true;
    }
    return false;
}

uint32_t getBits(const std::vector<uint8_t>& data, uint32_t bitPos, uint32_t bitLen) {
    uint32_t value = 0;

    for (uint32_t i = 0; i < bitLen; ++i) {
        uint32_t byteIndex = (bitPos + i) / 8;
        uint32_t bitIndex  = (bitPos + i) % 8;

        uint8_t bit = (data[byteIndex] >> bitIndex) & 1;
        value |= (bit << i);
    }
    return value;
}

/* ========================= Parser ========================= */

void parse_data(std::vector<uint8_t> frame) {

    if (frame.size() != 16) return;

    if (frame[0] != 0x68 || frame[1] != 0x0A ||
        frame[2] != 0x0A || frame[3] != 0x68) return;

    uint8_t sum = 0;
    for (int i = 4; i < 14; ++i) sum += frame[i];

    if (frame[14] != sum) return;
    if (frame[15] != 0x16) return;

    constexpr size_t DATA_START = 7;
    constexpr size_t DATA_LEN   = 16;

    std::vector<uint8_t> data(
        frame.begin() + DATA_START,
        frame.begin() + DATA_START + DATA_LEN
    );

    uint32_t millis  = getBits(data, 0, 10);
    uint32_t sec     = getBits(data, 10, 6);
    uint32_t min     = getBits(data, 16, 6);
    uint32_t hour    = getBits(data, 24, 5);
    bool     dst     = getBits(data, 31, 1);
    uint32_t day     = getBits(data, 32, 5);
    uint32_t weekday = getBits(data, 37, 3);
    uint32_t month   = getBits(data, 40, 4);
    uint32_t year    = getBits(data, 48, 7);

    std::cout << "TIME: 20" << year
              << "-" << std::setw(2) << std::setfill('0') << month
              << "-" << std::setw(2) << std::setfill('0') << day << " "
              << std::setw(2) << std::setfill('0') << hour << ":"
              << std::setw(2) << std::setfill('0') << min << ":"
              << std::setw(2) << std::setfill('0') << sec
              << "." << std::setw(3) << std::setfill('0') << millis
              << " , DST: " << (dst ? "[igen]" : "[nem]")
              << " , Wday: " << weekday << "\n";
}

/* ========================= MAIN ========================= */

int main(int argc, char* argv[]) {

    std::string fileName = (argc > 1) ? argv[1] : "./hga22.raw";
    printf("fileName: %s\r\n", fileName.c_str());

    std::ifstream f1(fileName, std::ios::binary);
    if (!f1.is_open()) {
        std::cerr << "Nem sikerült megnyitni a bemeneti fájlt!\n";
        return 1;
    }

    f1.seekg(0, std::ios::end);
    std::streamsize length = f1.tellg();
    f1.seekg(0, std::ios::beg);

    std::vector<unsigned char> buffer(length);
    f1.read(reinterpret_cast<char*>(buffer.data()), length);
    f1.close();

    int sample_time_ms    = 4;
    int samples_offset_ms = 1;

    int samples        = sample_time_ms * (SAMPLE_RATE / 1000);
    int samples_offset = samples_offset_ms * (SAMPLE_RATE / 1000);
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

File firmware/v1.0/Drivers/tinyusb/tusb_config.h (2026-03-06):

/*
 * The MIT License (MIT)
 *
 * Copyright (c) 2019 Ha Thach (tinyusb.org)
 *
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
 */

#ifndef TUSB_CONFIG_H_
#define TUSB_CONFIG_H_

#ifdef __cplusplus
extern "C" {
#endif

#include "lwipopts.h"

//--------------------------------------------------------------------+
// Board Specific Configuration
//--------------------------------------------------------------------+

// RHPort number used for device can be defined by board.mk, default to port 0
#ifndef BOARD_TUD_RHPORT
  #define BOARD_TUD_RHPORT 0
#endif

// RHPort max operational speed can defined by board.mk
#ifndef BOARD_TUD_MAX_SPEED
  #define BOARD_TUD_MAX_SPEED OPT_MODE_DEFAULT_SPEED
#endif

//--------------------------------------------------------------------
// Common Configuration
//--------------------------------------------------------------------

// defined by compiler flags for flexibility
#ifndef CFG_TUSB_MCU
  #error CFG_TUSB_MCU must be defined
#endif

#ifndef CFG_TUSB_OS
  #define CFG_TUSB_OS OPT_OS_NONE
#endif

#ifndef CFG_TUSB_DEBUG
  #define CFG_TUSB_DEBUG 0
#endif

// Enable Device stack
#define CFG_TUD_ENABLED 1

// Default is max speed that hardware controller could support with on-chip PHY
#define CFG_TUD_MAX_SPEED BOARD_TUD_MAX_SPEED

/* USB DMA on some MCUs can only access a specific SRAM region with restriction on alignment.
 * Tinyusb use follows macros to declare transferring memory so that they can be put
 * into those specific section.
 * e.g
 * - CFG_TUSB_MEM SECTION : __attribute__ (( section(".usb_ram") ))
 * - CFG_TUSB_MEM_ALIGN   : __attribute__ ((aligned(4)))
 */
#ifndef CFG_TUSB_MEM_SECTION
  #define CFG_TUSB_MEM_SECTION
#endif

#ifndef CFG_TUSB_MEM_ALIGN
  #define CFG_TUSB_MEM_ALIGN __attribute__((aligned(4)))
#endif
// Use different configurations to test all net devices (also due to resource limitations)
#ifndef USE_ECM
#if TU_CHECK_MCU(OPT_MCU_LPC15XX, OPT_MCU_LPC40XX, OPT_MCU_LPC51UXX, OPT_MCU_LPC54)
  #define USE_ECM 1
#elif TU_CHECK_MCU(OPT_MCU_SAMD21, OPT_MCU_SAML2X)
  #define USE_ECM 1
#elif TU_CHECK_MCU(OPT_MCU_STM32F0, OPT_MCU_STM32F1)
  #define USE_ECM 1
#elif TU_CHECK_MCU(OPT_MCU_MAX32690, OPT_MCU_MAX32650, OPT_MCU_MAX32666, OPT_MCU_MAX78002)
  #define USE_ECM 1
#else
  #define USE_ECM 0
  #define INCLUDE_IPERF
#endif
#endif

//--------------------------------------------------------------------
// NCM CLASS CONFIGURATION, SEE "ncm.h" FOR PERFORMANCE TUNING
//--------------------------------------------------------------------

// Must be >> MTU
// Can be set to 2048 without impact
#define CFG_TUD_NCM_IN_NTB_MAX_SIZE (2 * TCP_MSS + 100)

// Must be >> MTU
// Can be set to smaller values if wNtbOutMaxDatagrams==1
#define CFG_TUD_NCM_OUT_NTB_MAX_SIZE (2 * TCP_MSS + 100)

// Number of NCM transfer blocks for reception side
#ifndef CFG_TUD_NCM_OUT_NTB_N
  #define CFG_TUD_NCM_OUT_NTB_N 1
#endif

// Number of NCM transfer blocks for transmission side
#ifndef CFG_TUD_NCM_IN_NTB_N
  #define CFG_TUD_NCM_IN_NTB_N 1
#endif

//--------------------------------------------------------------------
// DEVICE CONFIGURATION
//--------------------------------------------------------------------

#ifndef CFG_TUD_ENDPOINT0_SIZE
  #define CFG_TUD_ENDPOINT0_SIZE 64
#endif

//------------- CLASS -------------//

// Network class has 2 drivers: ECM/RNDIS and NCM.
// Only one of the drivers can be enabled
#define CFG_TUD_ECM_RNDIS     USE_ECM
#define CFG_TUD_NCM           (1 - CFG_TUD_ECM_RNDIS)

#ifdef __cplusplus
}
#endif

#endif /* TUSB_CONFIG_H_ */

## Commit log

2026-03-06 Initial commit: HGA22 receiver
    [UNO_HGA22_V1.kicad_pcb, UNO_HGA22_V1.kicad_sch]
2026-03-13 Added Finished PCB and Gerber.
    [UNO_HGA22_V1.kicad_pcb]
2026-03-17 [FIX] Goertzel mag , adc oversample ,
    [adc.c, main.c, shell.c]
2026-03-23 Update HW Documentation. Fixing Schematic and PCB Silkscreen. Added generated Interactive BOM.
    [UNO_HGA22_V1.kicad_pcb, UNO_HGA22_V1.kicad_sch]
